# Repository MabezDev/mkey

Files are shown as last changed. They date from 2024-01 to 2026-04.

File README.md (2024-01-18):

## mKey

A mechanical keyboard based on an ESP32-S3, with firmware written in Rust.

[Click here to view the PCB & Schematic interactively in the browser](https://kicanvas.org/?github=https%3A%2F%2Fgithub.com%2FMabezDev%2Fmkey%2Ftree%2Fmain%2Fhardware%2Fboard)

## Flashing

The USB port is intended for flashing, as well as software USB usage. Version 1.0 of the board however has the DP and DM pins swapped, therefore to flash the board from the factory (or if the flash is wiped for any reason) you must flash via UART0. The pinout is as follows:

- TX is connected to the input side of D2 (COL1)
- RX is conncted to the input side of D3 (COL2)

## License

Licensed under either of:

- Apache License, Version 2.0 ([LICENSE-APACHE](LICENSE-APACHE) or http://www.apache.org/licenses/LICENSE-2.0)
- MIT license ([LICENSE-MIT](LICENSE-MIT) or http://opensource.org/licenses/MIT)
- CERN-OHL for the hardware files

at your option.

### Contribution

Unless you explicitly state otherwise, any contribution intentionally submitted for inclusion in
the work by you, as defined in the Apache-2.0 license, shall be dual licensed as above, without
any additional terms or conditions.

Contributions to the hardware will be licensed under the CERN-OHL license.

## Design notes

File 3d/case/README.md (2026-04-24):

# mKey Case — 3D Printing Build Guide

## Prerequisites

- [OpenSCAD](https://openscad.org/downloads.html) (CLI must be in `$PATH`)

## Quick Start

Export print-ready STLs for 3D printing:

```bash
cd 3d/case
./build_stl.sh
```

This produces `mkey_tray.stl` and `mkey_overlay.stl` in the current directory,
oriented for optimal printing (overlay flipped cosmetic-face-down, tray
bottom-down). Add supports in your slicer (Lychee, ChiTuBox, etc.).

> [!NOTE]
> **Run `./build_stl.sh` after every parameter or geometry change.** The
> build verifies that all assertions pass and that CGAL produces a valid
> mesh at production `$fn`. A clean OpenSCAD preview at low `$fn` does not
> guarantee a clean export — some CGAL errors only surface at `$fn=128`.

## Build Options

| Flag | Description |
|---|---|
| `--piece tray\|overlay\|both` | Which piece(s) to export (default: `both`) |
| `--fn N` | Circle resolution override (default: `128`; file preview default is `48`) |
| `--outdir DIR` | Output directory (default: `.`) |

## Print Orientation

The build script sets `PRINT_MODE=true`, which transforms the parts for
optimal 3D printing:

- **Overlay**: The 5-degree wedge tilt is removed so the part lies perfectly flat.
  The cosmetic face (key openings / display window) is flipped **down** toward
  the build plate — this gives the best surface finish on both SLA resin and FDM.

- **Tray**: Printed bottom-down (the bottom is already flat at Z=0). Add
  supports in the slicer — place them on outer walls and bottom only, not
  inside the cavity.

## Design Parameters (case.scad)

The main toggles in `case.scad` control which features are included:

| Toggle | Default | Purpose |
|---|---|---|
| `SHOW_TRAY` | `true` | Render the tray (bottom + walls) |
| `SHOW_OVERLAY` | `true` | Render the overlay (top surface) |
| `PRINT_MODE` | `false` | Re-orient pieces for 3D print export |
| `ENABLE_OVERLAY_RABBET` | `true` | Locating tongue/recess for X/Y registration |
| `ENABLE_MAGNET_POCKETS` | `true` | Blind magnet pockets for overlay hold-down |
| `ENABLE_SCREW_INSERTS` | `false` | M1.4 bolt + glued hex nut overlay retention (mutually exclusive with magnets) |
| `ENABLE_DECORATIVE_TRIMS` | `true` | Debossed logos, pinstripe, initials |

## JLC3DP SLA submission notes

> [!IMPORTANT]
> **X-AXIS SCALE COMPENSATION IS A HARD BUILD GATE.** Do not upload the
> STLs unless you have pasted the full order-note block below into the
> JLC3DP manufacturer-instructions field AND confirmed on the pre-build
> screenshot that JLC3DP applied the compensation on both pieces.
> Skipping this does not produce a looser fit — it produces parts that
> **physically cannot assemble**. The plate PCB is fabricated and frozen
> at its true size; the printed case without X-scale comp drifts up to
> ±1.09 mm over the 363 mm case length, which blows past every outer
> tolerance budget in the design (slot play, USB cheek, magnet margins).
>
> The geometry has belt-and-braces room for ±0.3 mm of residual post-
> compensation drift, not the raw ±1.09 mm uncompensated drift.

Paste the following instructions into the JLC3DP order-note / manufacturer-
instructions field when uploading `mkey_tray.stl` and `mkey_overlay.stl`.
Missing any of these will compromise fit or finish.

> Two-piece keyboard case, SLA standard resin.
>
> **MANDATORY — X-AXIS SCALE COMPENSATION ON BOTH PIECES:** Apply JLC3DP's
> per-batch X-axis scale compensation on BOTH `mkey_tray.stl` and
> `mkey_overlay.stl`. The case is 363 mm long and mates to a
> pre-fabricated FR4 PCB at tab positions spanning the full length; any
> asymmetric or uncompensated shrinkage will prevent assembly. Please
> confirm the compensation in your pre-build screenshots.
>
> **TRAY (mkey_tray.stl):**
> - Orient bottom-face DOWN on the build plate (the flat ~363 × 111 mm face).
>   Walls up, cavity open upward.
> - Factory supports on the outer side walls and outer bottom are acceptable.
>   **Do not add factory supports inside the cavity.**
> - The outer back wall carries a debossed "mKey" logo centred
>   horizontally, vertically between the bottom chamfer and the wall top
>   (~43 × 9 mm footprint). Please keep factory support contact points
>   clear of that debossed region if possible.
>
> **OVERLAY (mkey_overlay.stl):**
> - Orient cosmetic-face DOWN on the build plate (the face with the key
>   openings and display window). The underside, which carries the magnet
>   pockets (or hex nut pockets if using screw retention), faces up.
> - Place factory supports **only on the outer vertical side walls.** No
>   point supports on the downward-facing cosmetic face (key openings,
>   display window rim, pinstripe groove) and no supports inside the magnet
>   pockets, hex nut pockets, or display pocket on the up-facing underside. A raft under the
>   cosmetic face is acceptable provided the pinstripe groove and key
>   openings drain during post-processing (we IPA-flush these on our end).
> - **RAFT KEEP-OUT under the display window:** Please keep the raft
>   contact area clear of the ~32 × 38 mm region centred on the display
>   window cutout on the down-facing cosmetic face. The picture-frame
>   around the window is a 1.0 × 1.5 mm cross-grain rib — raft peel
>   forces can fracture it during support removal. An island of bare
>   build-plate under the window (with supports only on the surrounding
>   slab) is preferred.
>
> Please confirm orientations AND the X-axis scale compensation in the
> pre-build screenshots before starting the build.

**Why X-scale compensation is mandatory:** JLC3DP SLA has ±0.3% length
tolerance above 100 mm. At the 363 mm case X-axis that's ±1.09 mm worst
case, which would exceed the 0.6 mm slot tolerance on the outermost plate
tabs and shift the USB cutout off the receptacle body. With compensation,
residual drift is expected to stay inside the designed tolerances.

## Hand-finishing (post-delivery)

Order of operations when the parts arrive from JLC3DP:

1. **Inspect and photograph** factory support locations before removing
   anything — useful if a part has to be reordered.
2. **IPA-flush the resin-trap zones** with isopropanol and a soft brush
   *before* the final UV cure, if the factory hasn't already. These are
   recesses that sat against the build plate and may hold uncured resin:
    - Tray bottom underside: the `SM / 2026` owner-initials deboss.
    - Overlay cosmetic face: the pinstripe groove and (if enabled) the
      `DECO_LOGO_TOP` deboss.
3. **Snap off factory supports** from the tray bottom raft, tray outer
   walls, and overlay outer vertical walls. Expect witness nubbins —
   sand flat.
4. **Flush-sand the tray bottom** (raft side) with 120 → 240 → 400 grit,
   checking `SM / 2026` deboss legibility under raking light. Stop when
   legible; the 1.0 mm deboss depth tolerates ~0.3 mm of surface removal
   before legibility degrades.
5. **Light-sand the overlay outer vertical walls** (400 grit) to clean
   support nubbins. The cosmetic face should need only 800–1200 grit
   touch-up where any micro-support witness remains.
6. **Break the window edge** on the overlay with a fine file: the 1.0 mm
   shelf_frame_x on the display window long edges is at the brittle-
   fracture boundary under direct fingernail pressure during cleaning.
   A 0.2–0.3 mm edge break at all four window corners and edges
   multiplies its real-world durability.

## Fabrication Methods

**SLA resin (recommended)** — JLC3DP or equivalent. All tolerances and
minimum feature sizes are tuned for SLA's +/-0.2 mm accuracy. Add
supports in your slicer.

**MJF/SLS nylon** — NOT recommended. Loses the 1.0 mm shelf_frame_x display
window detail.

**FDM** — NOT suitable. Layer lines destroy the display cut tolerance and the
1.0 mm shelf frame sits below FDM's 1.6 mm wall minimum.

**Hand-cut hardwood** — Disable print-specific features:
```bash
# In case.scad or via -D flags:
ENABLE_DECORATIVE_TRIMS = false;
PRINT_MODE = false;
```

## Assembly

### Gasket install order

The plate is gasket-mounted: each of the 9 tabs is sandwiched between two
gasket strips inside its wall slot. Order matters — the plate cannot be
seated if the top gaskets are placed first.

1. **Bottom gaskets first.** Press a gasket strip into the bottom of each
   of the 9 slots before the plate goes in. These rest at the bottom of
   each slot, below where the tab will sit.
2. **Drop the plate in, front-first.** With 9 tabs engaging 9 slots
   simultaneously, a pure vertical descent is harder than a two-stage
   descent. Engage the 4 front tabs first (lower end of the tilted case),
   then **lower the plate straight down** — the 3 back tabs and 2 side
   tabs drop into their slots simultaneously. Do NOT pivot about the
   front tabs: a rotational descent swings the side tabs through ~3 mm
   of Z and can bind them against the wall top, which has only 1.5 mm
   of open-top margin. The 0.6 mm per-side slot tolerance accommodates
   the straight-down motion.
3. **Top gaskets second.** Press a second gasket strip onto the top of
   each tab, filling the remaining slot height.
4. **Overlay caps the stack.** Seating the overlay on the wall tops
   closes the open-top slots and compresses the top gaskets against the
   tabs, which compresses the tabs against the bottom gaskets.

### Magnet polarity

The overlay is held to the tray by six Ø2×1 mm N52 disc magnet pairs —
one per tray pocket and one per matching overlay pocket. Each pair must
**attract**, not repel, or the overlay will kick itself off the seat.

1. **Pick a reference magnet** from the bag and mark one face (dab of
   paint, sharpie dot). Set it aside.
2. **Tray magnets** — install every magnet with the **same face up** as
   the reference. Before each press-fit, hold the magnet face-up next to
   the reference: if they repel, flip it.
3. **Overlay magnets** — install with the **opposite face up**. When the
   overlay is flipped onto the tray, each overlay magnet then presents
   the attracting pole downward toward its tray mate. Test by holding
   the magnet with its eventual-up face touching the reference's
   marked face: it should **attract**.
4. **Glue each magnet FLUSH with the pocket mouth (critical).** The
   pockets are 2.0 mm deep for 1.0 mm magnets — if a magnet sinks to
   the pocket floor, the 1 mm recess on each side creates a 2 mm air
   gap that reduces holding force by ~90%. Place a flat reference plate
   (glass, steel straightedge) over the pocket mouth during CA cure so
   the magnet cures at the surface, not the bottom.
5. **Retain with thin CA glue (mandatory, not optional).** The 1.25 mm
   nominal cheek between pocket and outer wall (1.05 mm worst-case after
   SLA shrink) is too thin to rely on press-fit alone — any walk-out
   during thermal cycling or drop shock can chip the cheek. Use gel-type
   CA so it doesn't wick into the pocket and onto the seam, and press a
   strip of painter's tape across the pocket mouths during cure to prevent
   lift.

**Test before any glue cures.** With all 12 magnets placed but still
removable, lower the overlay onto the tray dry (no gaskets, no plate).
All six pairs should click together. If any pair repels, pop that
magnet out and flip it — catching this before the CA sets is much
cheaper than after.

### Screw + nut retention (alternative to magnets)

When `ENABLE_SCREW_INSERTS=true` (and `ENABLE_MAGNET_POCKETS=false`), the
overlay is secured by four M1.4 bolts threading up from inside the tray
into hex nuts glued into the overlay. Nothing is visible externally — bolt
heads sit in pockets on the tray underside (hidden against the desk),
and the overlay top surface is flush.

#### Hardware (4 of each)

| Qty | Part | Specification | Key dimensions |
|-----|---|---|---|
| 4 | Hex nut | M1.4 DIN 934 | 3.0 mm across-flats, 1.2 mm thick |
| 4 | Socket head cap screw | M1.4 × 14 mm | 2.6 mm head dia, 1.4 mm head height |

Same bolt length at all 4 positions. The bolt threads up from the tray
underside through the wall column and into the overlay nut. The through-
hole is a 4-segment stepped bore — no post-print drilling required:
- **Pocket** (3.4 mm dia, from tray bottom upward): bolt head sits here
- **Mid** (2.0 mm dia, intermediate): head catches on pocket→mid step
- **Lower clearance** (2.5 mm dia, 5.2 mm): wider pass-through
- **Upper clearance** (2.0 mm dia, 2.0 mm from wall top): shaft alignment

**Bolt length note:** M1.4 × 14 mm. The overlay nut pocket is 1.4 mm
deep — the 1.2 mm nut sits flush with the overlay underside (0.2 mm
tolerance headroom). 14 mm is the only standard M1.4 SHCS length that
simultaneously satisfies the mid-bore and back-pocket 3× depth rules;
12 mm fails the back pocket and 16 mm fails the mid bore.

Each segment stays within JLC3DP SLA depth limits (max 3× diameter) even
under worst-case ±0.3 mm hole-tolerance shrink.
At the back corners, the 10 mm chamfer removes the tray bottom; the
pocket starts from the chamfer face (deboss).

#### Nut installation

1. **Dry-fit first.** Drop each nut into its hex pocket on the overlay
   underside and confirm it sits flush with the surface. The pocket is
   only 0.2 mm deeper than the nut, so the nut should sit essentially
   flush by geometry. The hex shape should prevent rotation by hand.
   If a nut is tight, ream the pocket lightly with a needle file — do
   not force it.
2. **Glue with gel-type CA.** Apply a thin ring of gel CA around the
   pocket wall, press the nut in, and hold for 10 seconds. Wipe any
   squeeze-out immediately — excess CA on the overlay seating face will
   prevent the overlay from sitting flat on the tray.
3. **Do not use heat-set inserts.** SLA resin warps under soldering-iron
   temperatures. Glued hex nuts are the correct fastener for this process.

#### Final assembly

1. Complete the gasket + plate install (see above).
2. Seat the overlay on the tray wall tops (nuts face down, aligning
   with the clearance holes in the tray walls).
3. Flip the assembled case upside-down.
4. Insert the M1.4 × 14 mm bolts into all 4 pocket holes from below
   and tighten into the overlay nuts with a 1.25 mm hex key. Finger-
   tight plus a quarter turn is sufficient. **Hand-torque only — do
   NOT use a torque driver or electric screwdriver.** The bolt head
   bears on a 0.3 mm radial annulus between the Ø3.4 mm pocket and
   Ø2.0 mm mid segments (~2.2 mm² contact area); over-tightening will
   crush that step into the SLA resin and wander the pocket, which is
   not serviceable. If an overlay feels loose after the quarter turn,
   STOP and inspect — you will not fix it by tightening harder.
5. Flip the case back upright. The bolt heads sit in the pocket
   recesses on the tray underside, hidden against the desk.

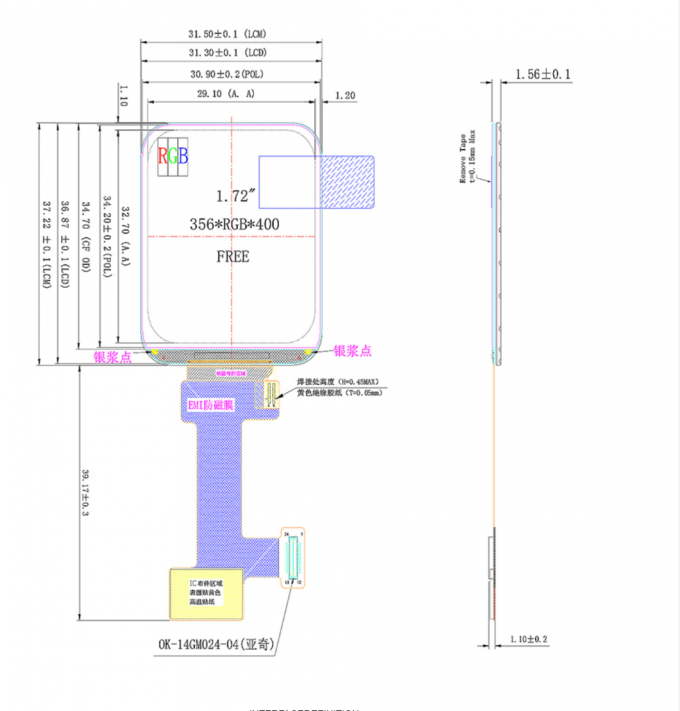
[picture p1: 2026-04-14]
hardware/board/assets/display-dimensions.png

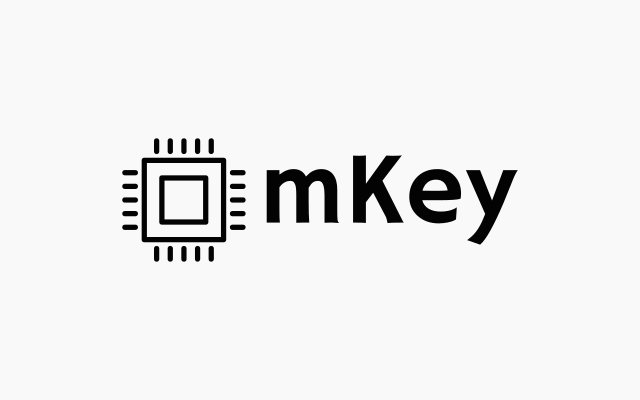
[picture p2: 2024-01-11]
hardware/board/assets/mkey.png

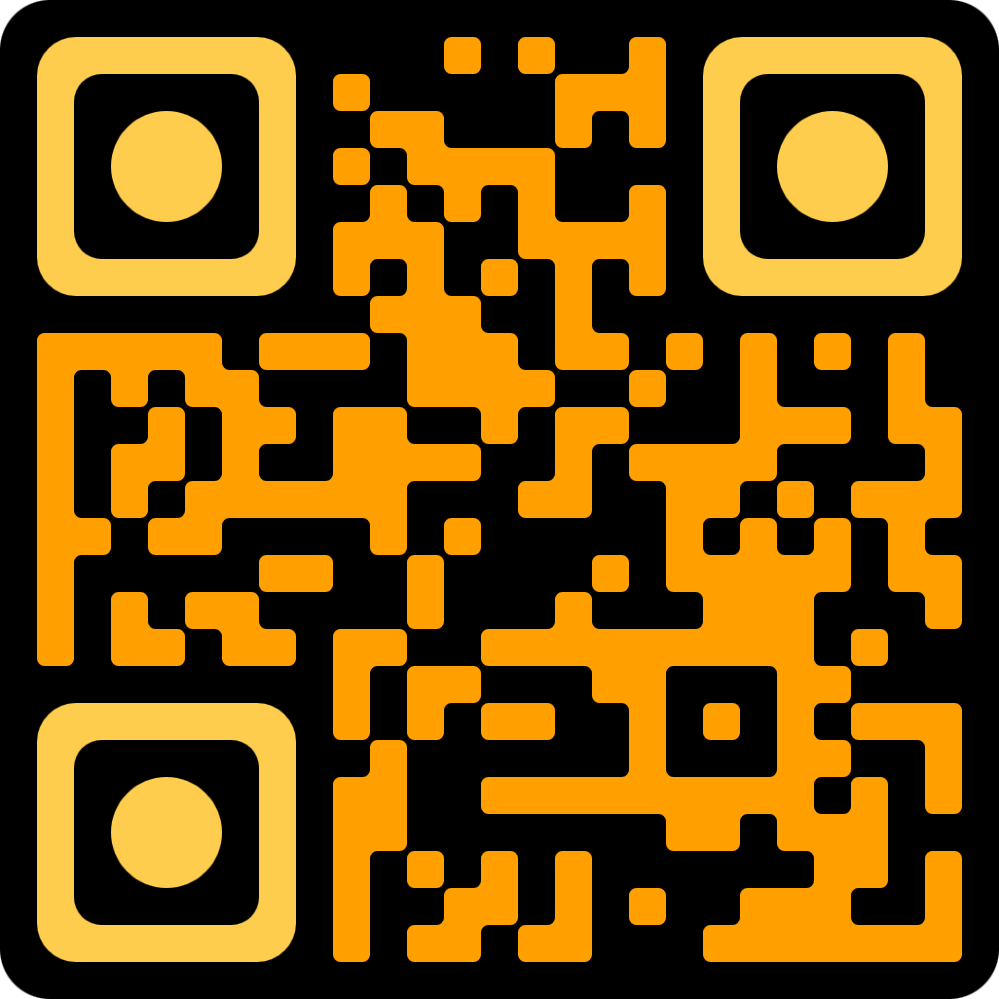
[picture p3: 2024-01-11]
hardware/board/assets/QR.png

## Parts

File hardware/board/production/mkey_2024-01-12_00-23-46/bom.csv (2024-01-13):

Designator | Footprint | Quantity | Value | LCSC Part #
_4, _3, _2, |  | 4
C1, C5 | 0603 | 2 | 1uF 16V | C52923
C2, C4 | 0805 | 2 | 10uF 16V | C15850
C3 | 0603 | 1 | 22pF 50V | C1653
C6 | 0603 | 1 | 100nF 10V | C1525
C7 | 0603 | 1 | 10nF 10V | C15195
D1, D10, D11, D12, D13, D14, D15, D16, D17, D18, D19, D2, D20, D21, D22, D23, D24, D25, D26, D27, D28, D29, D3, D30, D31, D32, D33, D34, D35, D36, D37, D38, D39, D4, D40, D41, D42, D43, D44, D45, D46, D47, D48, D49, D5, D50, D51, D52, D53, D54, D55, D56, D57, D58, D59, D6, D60, D61, D62, D63, D64, D65, D66, D7, D8, D9 | D_SOD-123 | 66 | D_Small
D67 | D_SOD-123 | 1 | B5819W | C8598
D68 | D_SOD-323 | 1 | PESD3V3L1BA,115
D69 | SOT-143 | 1 | SP0503BAHT
J1 | USB_C_Receptacle_HRO_TYPE-C-31-M-12 | 1 | USB_C_REP_2.0
J2 | CONN-SMD_24P-P0.40_X0400FVS-24-LPSN-LINEAR | 1 | 24 pin LCD FPC connector
L1 | L_Bourns-SRN4018 | 1 | SPH4018H2R2MT (2.2uH 2.2A) | C370436
MX1, MX10, MX11, MX12, MX13, MX14, MX16, MX17, MX18, MX19, MX2, MX20, MX21, MX22, MX23, MX24, MX25, MX26, MX27, MX28, MX3, MX30, MX31, MX32, MX33, MX34, MX35, MX36, MX37, MX38, MX39, MX4, MX40, MX41, MX43, MX44, MX45, MX46, MX47, MX48, MX49, MX5, MX50, MX51, MX52, MX53, MX54, MX55, MX59, MX6, MX64, MX65, MX66, MX7, MX8, MX9 | SW_MX_1u | 56 | MX_SW_solder
MX15 | SW_MX_1.5u | 1 | MX_SW_solder
MX29 | SW_MX_1.75u | 1 | MX_SW_solder
MX42, MX56, MX57, MX58, MX60, MX61, MX62, MX63 | SW_MX_1.25u | 8 | MX_SW_solder
R1, R2, R7 | 0603 | 3 | 10kR 1% | C25744
R3 | 0603 | 1 | 100kR 1% | C25741
R4 | 0603 | 1 | 22k1R 1% | C43473
R5, R6 | 0603 | 2 | 5k1R 1% | C25905
R8 | 0603 | 1 | 0R 1% | C17168
R9 | 0603 | 1 | 51.1R 1% | C25744
S1 | STAB_MX_P_6.25u | 1 | MX_stab
S2 | STAB_MX_P_2u | 1 | MX_stab
S4 | STAB_MX_P_2.75u | 1 | MX_stab
S5 | STAB_MX_ISO-ROT | 1 | MX_stab
SW0, SW1 | SW_SPST_PTS810 | 2 | SW_Push | C116501
U1 | ESP32-S3-WROOM-1 | 1 | ESP32-S3-WROOM-1
U2 | SOT-23-5 | 1 | SY8088 | C479072

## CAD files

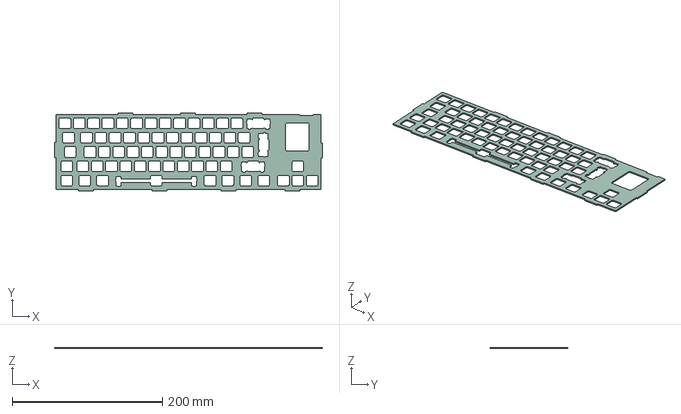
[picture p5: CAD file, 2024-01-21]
3d/plate.step
356.2 x 103.8 x 1.60 mm

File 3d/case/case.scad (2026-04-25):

// =============================================================================
// mKey Keyboard Case - OpenSCAD Design
// =============================================================================
// Premium darkwood case for the mKey 65% mechanical keyboard.
// Design: wedge profile, gasket-mounted plate, integrated display window.
// Style: sleek defined lines, minimal bezel, premium feel.
//
// FABRICATION TARGET — 3D PRINT PATH (JLC3DP SLA resin):
//   When fabricated by 3D print, the intended process is JLC3DP SLA resin
//   (standard photopolymer, e.g. 8001 / white resin). MJF/SLS nylon is NOT
//   suitable — it loses the 1.0 mm shelf_frame_x window detail. FDM is a
//   hard NO — layer lines destroy disp_cut_tol and the 1.0 mm shelf frame
//   sits below FDM's 1.6 mm wall minimum. Parameters in this file are tuned
//   to JLC3DP SLA's ±0.2 mm <100 mm / ±0.3% >100 mm tolerance band and
//   0.2 mm assembly-clearance rule; the 2026-04-14 pre-fab review
//   re-tightened disp_cut_tol and grew the locating tongue to clear those
//   rules with margin. Orient each piece bottom-up (cosmetic face away
//   from build plate); detailed print orientation is specified in the
//   manufacture notes.
//
// ╔════════════════════════════════════════════════════════════════════════╗
// ║  MANDATORY ORDER-NOTE REQUIREMENT — X-AXIS SCALE COMPENSATION         ║
// ║                                                                        ║
// ║  Before uploading `mkey_tray.stl` and `mkey_overlay.stl` to JLC3DP,   ║
// ║  you MUST paste the X-axis scale-compensation request into the        ║
// ║  order-note / manufacturer-instructions field. Without it, the parts  ║
// ║  will not assemble. This is not a preference; it is a hard build      ║
// ║  gate.                                                                 ║
// ║                                                                        ║
// ║  Why: the case outer_w is 363 mm. JLC3DP SLA tolerance over 100 mm    ║
// ║  is ±0.3% of the dimension → ±1.09 mm worst-case drift on X. The      ║
// ║  plate (FR4 PCB) is already fabricated and DOES NOT scale; printed    ║
// ║  slots at the outermost tabs can drift ~0.96 mm relative to their     ║
// ║  tabs, blowing past `slot_tol = 0.6 mm/side` and the 0.5 mm USB       ║
// ║  cheek and the 0.3 mm magnet-pocket wall margin. With per-piece       ║
// ║  X-scale compensation applied by JLC3DP, residual drift stays inside  ║
// ║  the tolerances the geometry was designed around.                     ║
// ║                                                                        ║
// ║  Action: see README.md §"JLC3DP SLA submission notes" — paste the     ║
// ║  full order-note block verbatim, do not abridge, and verify JLC3DP's  ║
// ║  pre-build screenshot confirms the scale compensation before          ║
// ║  production starts.                                                   ║
// ╚════════════════════════════════════════════════════════════════════════╝
//
// Coordinate system (case frame):
//   X = left to right (0 = left case edge)
//   Y = front to back (0 = front edge, positive toward back / USB side)
//   Z = up (0 = desk surface when case is sitting flat)
//
// Physical orientation (user sitting at keyboard):
//   Front (Y=0): spacebar row, lower edge (close to user)
//   Back (Y=max): number row, USB port, higher edge (away from user)
//   Right (X=max): display area, arrow keys
//   Left (X=0): Esc key side
// =============================================================================

$fn = 48;

// ─── Rendering switches ──────────────────────────────────────────────────────
SHOW_TRAY       = true;    // piece 1: bottom + walls
SHOW_OVERLAY    = true;    // piece 2: top surface
SHOW_PLATE      = false;   // ghost plate for fit check
SHOW_DISPLAY    = false;   // ghost display for fit check
SHOW_SECTION    = false;   // cross-section cut for inspection
EXPLODE         = 2;       // set >0 to separate overlay from tray (mm)

// ─── Print-mode switches ────────────────────────────────────────────────────
// When PRINT_MODE is true, the assembly renders print-oriented pieces:
//   - Overlay is flattened (6° tilt removed), bottom-up (pockets face up)
//   - Tray is unchanged in orientation (bottom is already flat)
// When exporting STLs for manufacturing, set PRINT_MODE=true and render one
// piece at a time (SHOW_TRAY xor SHOW_OVERLAY).
PRINT_MODE      = false;   // flip to true (or pass -D) for STL export

// ─── Feature toggles (per-fabrication-method overrides) ─────────────────────
// DESIGN NOTE — why these are toggles:
//   The case may be fabricated by two very different methods depending on the
//   build: (a) hand-cut hardwood using saw/drill/file/chisel, or (b) 3D-printed
//   plastic (FDM/SLA). Some features are trivial in one method and painful in
//   the other. A rabbet on the tray wall top to locate the overlay is ~5
//   minutes on a 3D-printer but a fiddly chisel operation in hardwood; blind
//   magnet pockets are laughably easy on a printer but need a drill-press stop
//   in wood. Rather than forking the file, every optional locating/retention
//   feature is behind a toggle so you can flip them per build without editing
//   the geometry. This is the real power of the file: one source, multiple
//   fabrication paths, with the asserts still covering all configurations.
ENABLE_OVERLAY_RABBET = true;    // cut a shallow rabbet in the tray wall top
                                 // that the overlay overhang seats into for
                                 // X/Y registration. Trivial on a printer,
                                 // chisel work in hardwood.
ENABLE_MAGNET_POCKETS = true;    // cut blind magnet pockets in the tray wall
                                 // top AND matching pockets in the overlay
                                 // underside, so the two pieces hold together
                                 // magnetically (serviceable — overlay lifts
                                 // off for PCB access). Counts on N52 disc
                                 // magnets — see magnet_* params below.
ENABLE_SCREW_INSERTS  = false;   // M1.4 hex nuts (glued) in hex pockets in the
                                 // overlay underside + bolts threading up from
                                 // the tray underside. 4 corner positions.
                                 // Mutually exclusive with ENABLE_MAGNET_POCKETS.

// ─── Decorative trims (3D-print-only) ───────────────────────────────────────
// Cosmetic embellishments with no mechanical role. Only practical on printed
// builds — hand-fabrication in hardwood can't render fine text/grooves cleanly.
// Every cut is sized to satisfy JLC3DP's design rules (≥0.8 mm wide AND
// ≥0.8 mm deep for any engraved or embossed detail, on both SLA resin and
// MJF nylon). ENABLE_DECORATIVE_TRIMS is the master gate: flipping it false
// silently drops every decorative cut, so hardwood builds or "naked" prints
// use the exact same file with one toggle.
ENABLE_DECORATIVE_TRIMS = true;   // master switch — false = all decoratives off
DECO_BACK_LOGO          = true;   // mKey logo debossed on outer back wall
DECO_EDGE_PINSTRIPE     = false;  // hairline groove around the overlay top edge
DECO_OWNER_INITIALS     = true;   // initials + year debossed into the tray underside
DECO_LOGO_TOP           = false;   // mKey logo debossed on overlay top above the display
DECO_INITIALS           = "SM";   // user-customisable owner initials
DECO_YEAR               = "2026"; // build year stamped under the initials

// =============================================================================
// SECTION 1: PLATE DIMENSIONS (from plate.kicad_pcb)
// =============================================================================
// The plate is the primary mounting reference. All case geometry derives from it.
//
// Plate KiCad coords:
//   Inner boundary: X 0.588..353.226, Y -107.641..-7.416
//   KiCad Y axis: negative, more negative = further up on screen = BACK of keyboard
//
// Plate-local coords (used in this file):
//   X_local = KiCad_X - 0.588       (0 = left plate edge)
//   Y_local = |KiCad_Y| - 7.416     (0 = front plate edge, plate_d = back)

plate_w = 352.638;   // inner boundary width  (353.226 - 0.588)
plate_d = 100.225;   // inner boundary depth  (107.641 - 7.416)
plate_t = 1.6;       // FR4 thickness

// ─── Mounting tabs ───────────────────────────────────────────────────────────
// Tabs extend beyond the inner boundary for gasket mounting.
// All positions in plate-local coordinates.
tab_len = 19.80;      // each tab is 19.80mm along its edge (measured in plate.kicad_pcb)
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

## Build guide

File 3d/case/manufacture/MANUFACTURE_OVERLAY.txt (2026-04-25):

X-axis scale compensation mandatory — ~350mm part, uncompensated shrinkage prevents mating.

Orientation: 26° X, 45° Z.

Supports: OK on underside flat areas away from pockets and perimeter edges. Heavy on underside to resist warping.

NO supports: top face (keycap side).

NO supports/sanding/blasting: display window rim, display pocket, 6 magnet pockets or 4 nut pockets (underside), rabbet recess (underside).

Confirm orientation and supports with screenshots before printing.

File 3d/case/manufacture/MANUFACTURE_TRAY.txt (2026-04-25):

X-axis scale compensation mandatory — ~350mm, shrinkage prevents mating.

Orientation: 26° X, 45° Z.

Drain holes: if needed, use rubber-pad recesses on underside.

Supports OK: outer walls, underside, perimeter edges, cavity. Heavy on underside for warp resistance.

NO supports/sanding/blasting: 9 gasket slots (inner walls), magnet pockets or screw holes (wall tops), USB-C cutout, rabbet tongue, debossed logo (back wall).

Confirm orientation and supports with screenshots.

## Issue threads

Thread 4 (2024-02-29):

Revision 1 board issues

MabezDev, 2024-02-29:
- [x] USB pins swapped
- [ ] Antenna clearance not enough
- [ ] Display CS tied to ground, CS is required to synchronize the display chip.

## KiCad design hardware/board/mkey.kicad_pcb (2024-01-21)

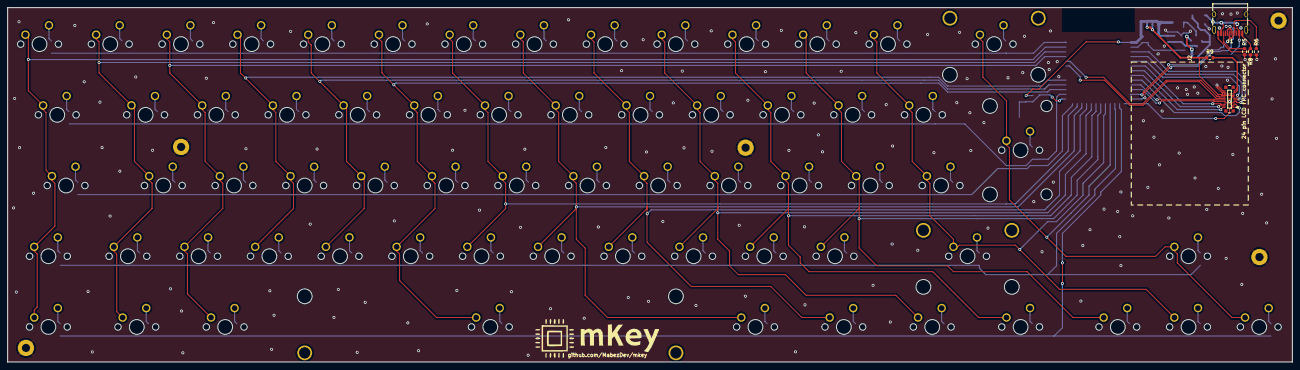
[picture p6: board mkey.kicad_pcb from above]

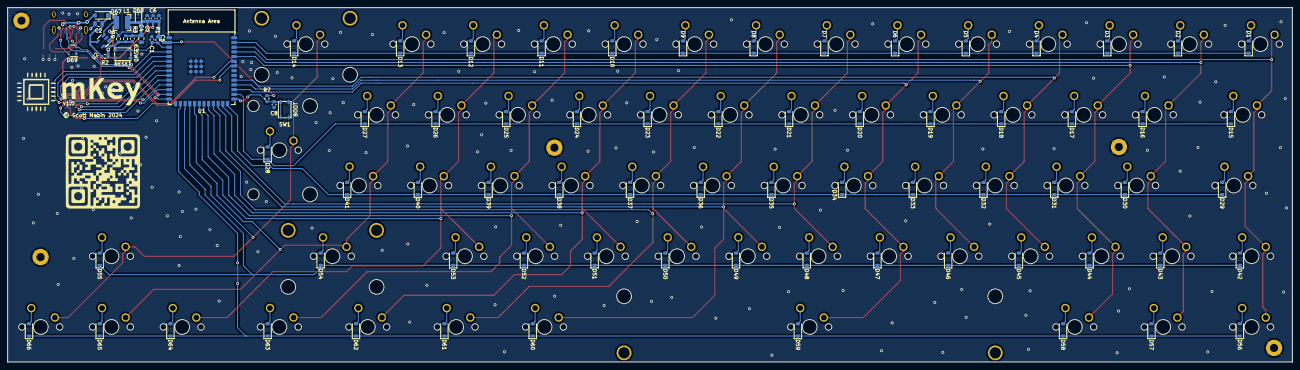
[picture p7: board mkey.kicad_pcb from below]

Board: 2 copper layers, 346.2 x 95.5 mm, 163 parts (87 on the bottom side), 112 nets.

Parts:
C1, C5: 1uF 16V; C_0603_1608Metric
C2, C4: 10uF 16V; C_0805_2012Metric
C3: 22pF 50V; C_0603_1608Metric
C6: 100nF 10V; C_0603_1608Metric
C7: 10nF 10V; C_0603_1608Metric
C8: 1nF 10V; C_0603_1608Metric
D1, D2, D3, D4, D5, D6, D7, D8, D9, D10, D11, D12, D13, D14, D15, D16, D17, D18, D19, D20, D21, D22, D23, D24, D25, D26, D27, D28, D29, D30, D31, D32, D33, D34, D35, D36, D37, D38, D39, D40, D41, D42, D43, D44, D45, D46, D47, D48, D49, D50, D51, D52, D53, D54, D55, D56, D57, D58, D59, D60, D61, D62, D63, D64, D65, D66: D_Small; D_SOD-123
D67: B5819W; D_SOD-123
D68: PESD3V3L1BA,115; D_SOD-323
D69: SP0503BAHT; SOT-143
J1: USB_C_REP_2.0; USB_C_Receptacle_HRO_TYPE-C-31-M-12
J2: 24 pin LCD FPC connector; CONN-SMD_24P-P0.40_X0400FVS-24-LPSN-LINEAR
L1: SPH4018H2R2MT (2.2uH 2.2A); L_Bourns-SRN4018
MX1, MX2, MX3, MX4, MX5, MX6, MX7, MX8, MX9, MX10, MX11, MX12, MX13, MX14, MX16, MX17, MX18, MX19, MX20, MX21, MX22, MX23, MX24, MX25, MX26, MX27, MX28, MX30, MX31, MX32, MX33, MX34, MX35, MX36, MX37, MX38, MX39, MX40, MX41, MX43, MX44, MX45, MX46, MX47, MX48, MX49, MX50, MX51, MX52, MX53, MX54, MX55, MX59, MX64, MX65, MX66: MX_SW_solder; SW_MX_1u
MX15: MX_SW_solder; SW_MX_1.5u
MX29: MX_SW_solder; SW_MX_1.75u
MX42, MX56, MX57, MX58, MX60, MX61, MX62, MX63: MX_SW_solder; SW_MX_1.25u
R1, R2, R7: 10kR 1%; R_0603_1608Metric
R3: 100kR 1%; R_0603_1608Metric
R4: 22k1R 1%; R_0603_1608Metric
R5, R6: 5k1R 1%; R_0603_1608Metric
R8: 0R 1%; R_0603_1608Metric
R9: 51.1R 1%; R_0603_1608Metric
S1: MX_stab; STAB_MX_P_6.25u
S2: MX_stab; STAB_MX_P_2u
S4: MX_stab; STAB_MX_P_2.75u
S5: MX_stab; STAB_MX_ISO-ROT
SW0, SW1: SW_Push; SW_SPST_PTS810
U1: ESP32-S3-WROOM-1
U2: SY8088; SOT-23-5

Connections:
+3V3: C3.1, C4.1, C5.1, C6.1, C7.1, D68.2 (A2), J2.9, J2.10, J2.15, J2.16, L1.2, R1.1, R3.1, R7.1, R9.2, U1.2 (3V3)
/Buck_Coil: L1.1, U2.3 (LX)
BOOT: C8.2, R7.2, SW1.1, U1.27 (GPIO0/BOOT)
CHIP_PU: C1.1, R1.2, SW0.1, U1.3 (EN)
COL0: MX1.1, MX15.1, MX29.1, MX42.1, MX56.1, U1.38 (GPIO2/TOUCH2/ADC1_CH1)
COL1: MX2.1, MX16.1, MX30.1, MX43.1, MX57.1, U1.37 (U0TXD/GPIO43/CLK_OUT1)
COL2: MX3.1, MX17.1, MX31.1, MX44.1, MX58.1, U1.36 (U0RXD/GPIO44/CLK_OUT2)
COL3: MX4.1, MX18.1, MX32.1, MX45.1, U1.31 (GPIO38/FSPIWP/SUBSPIWP)
COL4: MX5.1, MX19.1, MX33.1, MX46.1, U1.30 (SPIDQS/GPIO37/FSPIQ/SUBSPIQ)
COL5: MX6.1, MX20.1, MX34.1, MX47.1, MX59.1, U1.29 (SPIIO7/GPIO36/FSPICLK/SUBSPICLK)
COL6: MX7.1, MX21.1, MX35.1, MX48.1, U1.25 (GPIO48/SPICLK_N/SUBSPICLK_N_DIFF)
COL7: MX8.1, MX22.1, MX36.1, MX49.1, MX60.1, U1.24 (GPIO47/SPICLK_P/SUBSPICLK_P_DIFF)
COL8: MX9.1, MX23.1, MX37.1, MX50.1, MX61.1, U1.23 (GPIO21)
COL9: MX10.1, MX24.1, MX38.1, MX51.1, MX62.1, U1.22 (GPIO14/TOUCH14/ADC2_CH3/FSPIWP/FSPIDQS/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)
COL10: MX11.1, MX25.1, MX39.1, MX52.1, MX63.1, U1.21 (GPIO13/TOUCH13/ADC2_CH2/FSPIQ/FSPIIO7/S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)
COL11: MX12.1, MX26.1, MX40.1, MX53.1, MX64.1, U1.20 (GPIO12/TOUCH12/ADC2_CH1/FSPICLK/FSPIIO6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)
COL12: MX13.1, MX27.1, MX41.1, MX54.1, MX65.1, U1.19 (GPIO11/TOUCH11/ADC2_CH0/FSPID/FSPIIO5/S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)
COL13: MX14.1, MX28.1, MX55.1, MX66.1, U1.18 (GPIO10/TOUCH10/ADC1_CH9/FSPICS0/FSPIIO4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)
GND: C1.2, C2.2, C4.2, C5.2, C6.2, C7.2, C8.1, D68.1 (A1), D69.1 (A), J1.S1 (SHIELD), J2.2, J2.4, J2.8, J2.13, J2.14, J2.21, R4.2, R5.2, R6.2, R8.2, SW0.2, SW1.2, U1.1 (GND), U1.40 (GND), U1.41 (GND), U2.2 (GND)
LCD_CLK: J2.5, U1.4 (GPIO4/TOUCH4/ADC1_CH3)
LCD_D/C: J2.24, U1.9 (GPIO16/U0CTS/ADC2_CH5/XTAL_32K_N)
LCD_RESET: J2.1, U1.15 (GPIO3/TOUCH3/ADC1_CH2)
LCD_SIO0: J2.7, U1.6 (GPIO6/TOUCH6/ADC1_CH5)
LCD_SIO1: J2.6, U1.5 (GPIO5/TOUCH5/ADC1_CH4)
LCD_SIO2: J2.23, U1.8 (GPIO15/U0RTS/ADC2_CH4/XTAL_32K_P)
LCD_SIO3: J2.22, U1.7 (GPIO7/TOUCH7/ADC1_CH6)
unnamed: D1.2 (A), MX1.2
unnamed: D2.2 (A), MX2.2
unnamed: D3.2 (A), MX3.2
unnamed: D4.2 (A), MX4.2
unnamed: D5.2 (A), MX5.2
unnamed: D6.2 (A), MX6.2
unnamed: D7.2 (A), MX7.2
unnamed: D8.2 (A), MX8.2
unnamed: D9.2 (A), MX9.2
unnamed: D10.2 (A), MX10.2
unnamed: D11.2 (A), MX11.2
unnamed: D12.2 (A), MX12.2
unnamed: D13.2 (A), MX13.2
unnamed: D14.2 (A), MX14.2
unnamed: D15.2 (A), MX15.2
unnamed: D16.2 (A), MX16.2
unnamed: D17.2 (A), MX17.2
unnamed: D18.2 (A), MX18.2
unnamed: D19.2 (A), MX19.2
unnamed: D20.2 (A), MX20.2
unnamed: D21.2 (A), MX21.2
unnamed: D22.2 (A), MX22.2
unnamed: D23.2 (A), MX23.2
unnamed: D24.2 (A), MX24.2
unnamed: D25.2 (A), MX25.2
unnamed: D26.2 (A), MX26.2
unnamed: D27.2 (A), MX27.2
unnamed: D28.2 (A), MX28.2
unnamed: D29.2 (A), MX29.2
unnamed: D30.2 (A), MX30.2
unnamed: D31.2 (A), MX31.2
unnamed: D32.2 (A), MX32.2
unnamed: D33.2 (A), MX33.2
unnamed: D34.2 (A), MX34.2
unnamed: D35.2 (A), MX35.2
unnamed: D36.2 (A), MX36.2
unnamed: D37.2 (A), MX37.2
unnamed: D38.2 (A), MX38.2
unnamed: D39.2 (A), MX39.2
unnamed: D40.2 (A), MX40.2
unnamed: D41.2 (A), MX41.2
unnamed: D42.2 (A), MX42.2
unnamed: D43.2 (A), MX43.2
unnamed: D44.2 (A), MX44.2
unnamed: D45.2 (A), MX45.2
unnamed: D46.2 (A), MX46.2
unnamed: D47.2 (A), MX47.2
unnamed: D48.2 (A), MX48.2
unnamed: D49.2 (A), MX49.2
unnamed: D50.2 (A), MX50.2
unnamed: D51.2 (A), MX51.2
unnamed: D52.2 (A), MX52.2
unnamed: D53.2 (A), MX53.2
unnamed: D54.2 (A), MX54.2
unnamed: D55.2 (A), MX55.2
unnamed: D56.2 (A), MX56.2
unnamed: D57.2 (A), MX57.2
unnamed: D58.2 (A), MX58.2
unnamed: D59.2 (A), MX59.2
unnamed: D60.2 (A), MX60.2
unnamed: D61.2 (A), MX61.2
unnamed: D62.2 (A), MX62.2
unnamed: D63.2 (A), MX63.2
unnamed: D64.2 (A), MX64.2
unnamed: D65.2 (A), MX65.2
unnamed: D66.2 (A), MX66.2
unnamed: D67.2 (A), D69.4 (K), J1.A4 (VBUS), J1.A9 (VBUS), J1.B4 (VBUS), J1.B9 (VBUS)
unnamed: J1.A5 (CC1), R6.1
unnamed: J1.B5 (CC2), R5.1
unnamed: J1.A1 (GND), J1.A12 (GND), J1.B1 (GND), J1.B12 (GND), R8.1
unnamed: J2.11, J2.12, R9.1
unnamed: R2.2, U2.1 (EN)
unnamed: C3.2, R3.2, R4.1, U2.5 (FB)
ROW0: D1.1 (K), D2.1 (K), D3.1 (K), D4.1 (K), D5.1 (K), D6.1 (K), D7.1 (K), D8.1 (K), D9.1 (K), D10.1 (K), D11.1 (K), D12.1 (K), D13.1 (K), D14.1 (K), U1.39 (GPIO1/TOUCH1/ADC1_CH0)
ROW1: D15.1 (K), D16.1 (K), D17.1 (K), D18.1 (K), D19.1 (K), D20.1 (K), D21.1 (K), D22.1 (K), D23.1 (K), D24.1 (K), D25.1 (K), D26.1 (K), D27.1 (K), D28.1 (K), U1.28 (SPIIO6/GPIO35/FSPID/SUBSPID)
ROW2: D29.1 (K), D30.1 (K), D31.1 (K), D32.1 (K), D33.1 (K), D34.1 (K), D35.1 (K), D36.1 (K), D37.1 (K), D38.1 (K), D39.1 (K), D40.1 (K), D41.1 (K), U1.26 (GPIO45)
ROW3: D42.1 (K), D43.1 (K), D44.1 (K), D45.1 (K), D46.1 (K), D47.1 (K), D48.1 (K), D49.1 (K), D50.1 (K), D51.1 (K), D52.1 (K), D53.1 (K), D54.1 (K), D55.1 (K), U1.17 (GPIO9/TOUCH9/ADC1_CH8/FSPIHD/SUBSPIHD)
ROW4: D56.1 (K), D57.1 (K), D58.1 (K), D59.1 (K), D60.1 (K), D61.1 (K), D62.1 (K), D63.1 (K), D64.1 (K), D65.1 (K), D66.1 (K), U1.16 (GPIO46)
TEAR EFFECT: J2.3, U1.10 (GPIO17/U1TXD/ADC2_CH6)
TP_INT: J2.17, U1.35 (MTMS/GPIO42)
TP_RST: J2.18, U1.34 (MTDI/GPIO41/CLK_OUT1)
TP_SCL: J2.20, U1.12 (GPIO8/TOUCH8/ADC1_CH7/SUBSPICS1)
TP_SDA: J2.19, U1.11 (GPIO18/U1RXD/ADC2_CH7/CLK_OUT3)
USB_D+: D69.3 (K), J1.A6 (D+), J1.B6 (D+), U1.14 (GPIO20/U1CTS/ADC2_CH9/CLK_OUT1/USB_D+)
USB_D-: D69.2 (K), J1.A7 (D-), J1.B7 (D-), U1.13 (GPIO19/U1RTS/ADC2_CH8/CLK_OUT2/USB_D-)
VBUS: C2.1, D67.1 (K), R2.1, U2.4 (IN)

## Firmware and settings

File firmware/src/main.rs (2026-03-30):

#![no_std]
#![no_main]
#![feature(type_alias_impl_trait)]

use core::ptr::addr_of_mut;
use core::sync::atomic::Ordering;

use embassy_sync::blocking_mutex::raw::CriticalSectionRawMutex;
use embassy_sync::signal::Signal;
use embedded_graphics::geometry::Point;
use embedded_graphics::image::Image;
use embedded_graphics::Drawable;
use embedded_graphics_core::pixelcolor::Rgb565;
// esp-backtrace still linked for backtrace support, but our own panic handler
// in panic.rs saves the message to RTC memory before resetting.
use esp_hal::clock::CpuClock;
use esp_hal::dma::DmaRxBuf;
use esp_hal::dma::DmaTxBuf;
use esp_hal::dma_buffers;
use esp_hal::gpio::InputConfig;
use esp_hal::gpio::Level;
use esp_hal::interrupt;
use esp_hal::interrupt::software::SoftwareInterruptControl;
use esp_hal::interrupt::Priority;
use esp_hal::otg_fs::Usb;
use esp_hal::peripherals::Interrupt;
use esp_hal::system::Stack;
use esp_hal::time::Rate;
use esp_hal::timer::systimer::SystemTimer;
use esp_hal::timer::timg::TimerGroup;
use esp_hal::{
    delay::Delay,
    gpio::Io,
    gpio::{Input, Output, Pull},
    main,
    spi::{master::Spi, Mode},
};
use esp_rtos::{self, embassy::Executor};
use usbd_hid::descriptor::KeyboardReport;

use display::{
    lcd_fill, lcd_write_cmd, FRAME_BUFFER, HEIGHT, MAX_DMA_TRANSFER, TE, TE_READY,
    WEA2012_INIT_CMDS, WIDTH,
};

#[macro_export]
macro_rules! make_static {
    ($t:ty, $val:expr) => ($crate::make_static!($t, $val,));
    ($t:ty, $val:expr, $(#[$m:meta])*) => {{
        $(#[$m])*
        static STATIC_CELL: static_cell::StaticCell<$t> = static_cell::StaticCell::new();
        STATIC_CELL.init_with(|| $val)
    }};
}

esp_bootloader_esp_idf::esp_app_desc!();

// MUST be the first module so other modules see the macros
pub mod fmt;

mod display;
mod keyboard;
mod keymap;
mod logger;
mod panic;

static mut APP_CORE_STACK: Stack<8192> = Stack::new();

#[main]
fn main() -> ! {
    let peripherals = esp_hal::init(esp_hal::Config::default().with_cpu_clock(CpuClock::max()));

    let debug = cfg!(feature = "debug-matrix") || keyboard::is_debug_mode();

    // Check for panic from previous boot — message will be sent over CDC once USB enumerates
    panic::check_previous_panic();

    // Logger just pushes to a pipe — consumer (CDC or JTAG) is set up later on core 1
    logger::init();

    let delay = Delay::new();

    let timg0 = TimerGroup::new(peripherals.TIMG0);
    esp_rtos::start(timg0.timer0);

    let mut io = Io::new(peripherals.IO_MUX);
    io.set_interrupt_handler(display::te);
    interrupt::enable(Interrupt::GPIO, Priority::Priority2).unwrap();

    let sclk = peripherals.GPIO4;
    let sio0 = peripherals.GPIO6;
    let sio1 = peripherals.GPIO5;
    let sio2 = peripherals.GPIO15;
    let sio3 = peripherals.GPIO7;
    let cs = peripherals.GPIO16;
    let mut reset = Output::new(peripherals.GPIO3, Level::Low, Default::default());

    let mut te_pin = Input::new(
        peripherals.GPIO17,
        InputConfig::default().with_pull(Pull::Down),
    );
    te_pin.listen(esp_hal::gpio::Event::RisingEdge);
    critical_section::with(|cs| TE.borrow_ref_mut(cs).replace(te_pin));

    let (tx_buffer, tx_descriptors, rx_buffer, rx_descriptors) = dma_buffers!(MAX_DMA_TRANSFER, 1);

    let mut spi = Spi::new(
        peripherals.SPI2,
        esp_hal::spi::master::Config::default()
            .with_frequency(Rate::from_mhz(80))
            .with_mode(Mode::_3),
    )
    .unwrap()
    .with_sck(sclk)
    .with_mosi(sio0)
    .with_miso(sio1)
    .with_sio2(sio2)
    .with_sio3(sio3)
    .with_cs(cs)
    .with_dma(peripherals.DMA_CH0)
    .with_buffers(
        DmaRxBuf::new(rx_descriptors, rx_buffer).unwrap(),
        DmaTxBuf::new(tx_descriptors, tx_buffer).unwrap(),
    );

    reset.set_low();
    delay.delay_millis(300u32);
    reset.set_high();
    delay.delay_millis(300u32);

    // initialization commands
    for (cmd, data) in WEA2012_INIT_CMDS {
        lcd_write_cmd(&mut spi, *cmd, data);
    }
    info!("Finished initializing display!");

    let pixels = unsafe { &mut *addr_of_mut!(FRAME_BUFFER) };
    /*
       Matrix
    */
    let columns = make_static!(
        [Input<'static>; 14],
        [
            Input::new(
                peripherals.GPIO2,
                InputConfig::default().with_pull(Pull::Up)
            ), // 0
            Input::new(
                peripherals.GPIO43,
                InputConfig::default().with_pull(Pull::Up)
            ), // 1
            Input::new(
                peripherals.GPIO44,
                InputConfig::default().with_pull(Pull::Up)
            ), // 2
            Input::new(
                peripherals.GPIO38,
                InputConfig::default().with_pull(Pull::Up)
            ), // 3
            Input::new(
                peripherals.GPIO37,
                InputConfig::default().with_pull(Pull::Up)
            ), // 4
            Input::new(
                peripherals.GPIO36,
                InputConfig::default().with_pull(Pull::Up)
            ), // 5
            Input::new(
                peripherals.GPIO48,
                InputConfig::default().with_pull(Pull::Up)
            ), // 6
            Input::new(
                peripherals.GPIO47,
                InputConfig::default().with_pull(Pull::Up)
            ), // 7
            Input::new(
                peripherals.GPIO21,
                InputConfig::default().with_pull(Pull::Up)
            ), // 8
            Input::new(
                peripherals.GPIO14,
                InputConfig::default().with_pull(Pull::Up)
            ), // 9
            Input::new(
                peripherals.GPIO13,
                InputConfig::default().with_pull(Pull::Up)
            ), // 10
            Input::new(
                peripherals.GPIO12,
                InputConfig::default().with_pull(Pull::Up)
            ), // 11
            Input::new(
                peripherals.GPIO11,
                InputConfig::default().with_pull(Pull::Up)
            ), // 12
            Input::new(
                peripherals.GPIO10,
                InputConfig::default().with_pull(Pull::Up)
            ), // 13
        ]
    );
    let rows = make_static!(
        [Output<'static>; 5],
        [
            Output::new(peripherals.GPIO1, Level::Low, Default::default()), // 0
            Output::new(peripherals.GPIO35, Level::Low, Default::default()), // 1
            Output::new(peripherals.GPIO45, Level::Low, Default::default()), // 2
            Output::new(peripherals.GPIO9, Level::Low, Default::default()), // 3
            Output::new(peripherals.GPIO46, Level::Low, Default::default()), // 4
        ]
    );

    let sw_ints = SoftwareInterruptControl::new(peripherals.SW_INTERRUPT);
    esp_rtos::start_second_core(
        peripherals.CPU_CTRL,
        sw_ints.software_interrupt0,
        sw_ints.software_interrupt1,
        unsafe { &mut *addr_of_mut!(APP_CORE_STACK) },
        move || {
            let signal =
                &*make_static!(Signal<CriticalSectionRawMutex, KeyboardReport>, Signal::new());
            let executor = make_static!(Executor, Executor::new());

            if debug {
                let usb_serial =
                    esp_hal::usb_serial_jtag::UsbSerialJtag::new(peripherals.USB_DEVICE);
                let (_rx, tx) = usb_serial.split();
                executor.run(|spawner| {
                    spawner.must_spawn(keyboard::matrix(columns, rows, signal));
                    spawner.must_spawn(keyboard::jtag_drain(tx));
                });
            } else {
                let device = Usb::new(peripherals.USB0, peripherals.GPIO20, peripherals.GPIO19);
                executor.run(|spawner| {
                    spawner.must_spawn(keyboard::matrix(columns, rows, signal));
                    spawner.must_spawn(keyboard::usb(device, signal));
                });
            }
        },
    );

    let image =
        tinygif::Gif::<Rgb565>::from_slice(include_bytes!("../Ferris-240x240.gif")).unwrap();
    let mut start = SystemTimer::unit_value(esp_hal::timer::systimer::Unit::Unit0);
    let mut frames = 0;
    loop {
        for frame in image.frames() {
            let frame = Image::with_center(
                &frame,
                Point::new(WIDTH as i32 / 2, (HEIGHT as i32 / 2) - 40),
            );
            frame.draw(pixels).unwrap();

            // TE_READY won't get set until we mark that we're ready to flush a buffer
            critical_section::with(|cs| {
                TE_READY.store(false, Ordering::SeqCst);
                TE.borrow_ref_mut(cs).as_mut().unwrap().clear_interrupt();
            });
            // wait for next sync
            while !TE_READY.load(Ordering::SeqCst) {}

            let pixels = unsafe {
                core::slice::from_raw_parts(
                    pixels.data().as_ptr() as *const u8,
                    pixels.data().len(),
                )
            };
            let now = SystemTimer::unit_value(esp_hal::timer::systimer::Unit::Unit0);
            lcd_fill(&mut spi, pixels);
            trace!(
                "Time to fill display: {}ms",
                (SystemTimer::unit_value(esp_hal::timer::systimer::Unit::Unit0) - now)
                    / (SystemTimer::ticks_per_second() / 1024)
            );
            frames += 1;
            let now = SystemTimer::unit_value(esp_hal::timer::systimer::Unit::Unit0);
            if now.wrapping_sub(start) > SystemTimer::ticks_per_second() {
                start = now;
                info!("FPS: {}", frames);
                frames = 0;
            }
        }
    }
}

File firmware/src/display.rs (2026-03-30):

use core::cell::RefCell;
use core::ptr::addr_of_mut;
use core::sync::atomic::AtomicBool;
use core::sync::atomic::Ordering;

use critical_section::Mutex;
use embedded_graphics::framebuffer::buffer_size;
use embedded_graphics::framebuffer::Framebuffer;
use embedded_graphics::pixelcolor::raw::BigEndian;
use embedded_graphics::pixelcolor::raw::RawU16;
use embedded_graphics_core::pixelcolor::Rgb565;
use esp_hal::gpio::Input;
use esp_hal::spi::master::{Address, Command, DataMode};
use esp_hal::timer::systimer::SystemTimer;
use esp_hal::Blocking;
use esp_hal::{handler, ram};

pub type QSpiDisplay<'a> = esp_hal::spi::master::SpiDmaBus<'a, Blocking>;

pub const MAX_DMA_TRANSFER: usize = 32736 / 4;
pub const WIDTH: usize = 356;
pub const HEIGHT: usize = 400;

pub static TE: Mutex<RefCell<Option<Input<'static>>>> = Mutex::new(RefCell::new(None));
pub static TE_READY: AtomicBool = AtomicBool::new(false);

pub static mut FRAME_BUFFER: Framebuffer<
    Rgb565,
    RawU16,
    BigEndian,
    WIDTH,
    HEIGHT,
    { buffer_size::<Rgb565>(WIDTH, HEIGHT) },
> = Framebuffer::new();

#[handler]
pub fn te() {
    unsafe {
        static mut LAST: u64 = 0;
        let now = SystemTimer::unit_value(esp_hal::timer::systimer::Unit::Unit0);
        log::trace!(
            "TE fired! Interval: {}ms",
            (now - LAST) / (SystemTimer::ticks_per_second() / 1024)
        );
        LAST = now;
    }
    critical_section::with(|cs| TE.borrow_ref_mut(cs).as_mut().unwrap().clear_interrupt());
    TE_READY.store(true, Ordering::SeqCst);
}

#[ram]
pub fn lcd_fill<'a>(spi: &mut QSpiDisplay<'a>, pixels: &'static [u8]) {
    set_draw_area(spi, 0, 0, WIDTH as u16 - 1, HEIGHT as u16 - 1);
    for (i, pixels) in pixels.chunks(MAX_DMA_TRANSFER).enumerate() {
        // fifo size
        spi.half_duplex_write(
            DataMode::Quad,
            Command::_8Bit(0x32, DataMode::SingleTwoDataLines),
            Address::_24Bit(
                if i > 0 { 0x002C00 } else { 0x003C00 },
                DataMode::SingleTwoDataLines,
            ),
            0,
            &pixels,
        )
        .unwrap();
    }
}

#[ram]
pub fn lcd_write_cmd<'a>(spi: &mut QSpiDisplay<'a>, cmd: u32, data: &[u8]) {
    static mut BUF: [u8; 4] = [0u8; 4];
    let buf = unsafe { &mut *addr_of_mut!(BUF) };
    if data.len() > 0 {
        buf[..data.len()].copy_from_slice(&data);
    }
    log::trace!("Sending: {} => {:?}", cmd, &buf[..data.len()]);
    spi.half_duplex_write(
        DataMode::Single,
        Command::_8Bit(0x02, DataMode::Single),
        Address::_24Bit(cmd << 8, DataMode::Single),
        0,
        &&buf[..data.len()],
    )
    .unwrap();
}

#[ram]
fn set_draw_area<'a>(spi: &mut QSpiDisplay<'a>, x1: u16, y1: u16, x2: u16, y2: u16) {
    let cmds = [
        (
            0x2a,
            &[(x1 >> 8) as u8, x1 as u8, (x2 >> 8) as u8, x2 as u8][..],
        ),
        (
            0x2b,
            &[(y1 >> 8) as u8, y1 as u8, (y2 >> 8) as u8, y2 as u8][..],
        ),
    ];

    for (cmd, data) in cmds {
        lcd_write_cmd(spi, cmd, data);
    }
}

// CMD, data
pub const WEA2012_INIT_CMDS: &[(u32, &[u8])] = &[
    (0xFF, &[0x20, 0x10, 0x43]),
    (0x04, &[0x70]),
    (0xFF, &[0x20, 0x10, 0x10]),
    (0x0C, &[0x11]),
    (0x10, &[0x02]),
    (0x11, &[0x11]),
    (0x15, &[0x42]),
    (0x16, &[0x11]),
    (0x1A, &[0x02]),
    (0x1B, &[0x11]),
    (0x61, &[0x80]),
    (0x62, &[0x80]),
    (0x54, &[0x44]),
    (0x58, &[0x88]),
    (0x5C, &[0xcc]),
    (0x20, &[0x80]),
    (0x21, &[0x81]),
    (0x22, &[0x31]),
    (0x23, &[0x20]),
    (0x24, &[0x11]),
    (0x25, &[0x11]),
    (0x26, &[0x12]),
    (0x27, &[0x12]),
    (0x30, &[0x80]),
    (0x31, &[0x81]),
    (0x32, &[0x31]),
    (0x33, &[0x20]),
    (0x34, &[0x11]),
    (0x35, &[0x11]),
    (0x36, &[0x12]),
    (0x37, &[0x12]),
    (0x41, &[0x11]),
    (0x42, &[0x22]),
    (0x43, &[0x33]),
    (0x49, &[0x11]),
    (0x4A, &[0x22]),
    (0x4B, &[0x33]),
    (0xFF, &[0x20, 0x10, 0x15]),
    (0x00, &[0x00]),
    (0x01, &[0x00]),
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
    // touch For I2C
    (0xFF, &[0x20, 0x10, 0x50]),
    (0x05, &[0x00]),
    (0x00, &[0xA6]),
    (0x01, &[0xA6]),
    (0x08, &[0x55]),
    (0xFF, &[0x20, 0x10, 0x12]),
    (0x21, &[0xB4]), // set vcom
    (0xFF, &[0x20, 0x10, 0x00]),
    // ADD FOR QSPI/TP TEST
    (0x3A, &[0x05]), // Set 65K colour mode
    (0x11, &[0x00]),
    (0x29, &[0x00]),
];

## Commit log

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2024-01-18 qio working? can read back some values, one seems correct, the other does not match the reset value...
    [main.rs]
2024-01-19 imo everything is correct, time to wait for new display and or get logic analyser on it
    [main.rs]
2024-01-21 Fix plate dims, remove old plates, add new plate with prod files
    [designators.csv, mkey-plate.kicad_pcb, plate.kicad_pcb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]
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2024-01-21 move lib back to board, kicad doesn't seem to follow paths outside of the proj. Add 3d model to usb port
    [mkey.kicad_pcb]
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2026-03-29 add UK ISO keymap with debounced matrix scanning and proper HID reports
    Replace the placeholder 'always send A' logic with a full keymap-driven
    approach: a 5×14 KEYMAP table maps each (row, col) to HID keycodes and
    modifier bits, the matrix task debounces key state and builds complete
    KeyboardReports (6KRO + modifiers), and the USB task forwards them directly.
    [main.rs]
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2026-03-29 fix keymap to match schematic and add debug-matrix feature
    Align keymap with actual PCB wiring from KiCad schematic:
    - Enter switch is at (row1, col13), row2/col13 has no switch
    - Space switch is at (row4, col4), not spread across cols 3-8
    - MX60 (row4, col7) is RAlt, MX61 (row4, col8) is Fn placeholder
    - Empty matrix positions marked with __ instead of duplicate keycodes
    Add debug-matrix cargo feature that skips USB init (preserving JTAG
    serial logging) and logs key press/release events with HID codes.
    [main.rs]
2026-03-30 add Fn key debug combos and runtime debug mode switching
    Fn key (row 4, col 8) now acts as a firmware-level modifier:
    - Fn + Esc: software reset
    - Fn + Backspace: reset to USB download mode
    - Fn + D: toggle debug mode (persisted in RTC store register)
    Debug mode is now runtime-switchable: Fn+D sets a flag in RTC memory
    that survives soft resets, so the next boot skips USB OTG init and
    runs JTAG serial logging instead. Fn+D again clears the flag and
    reboots back to normal USB HID mode. The debug-matrix cargo feature
    still works as a compile-time override.
    When Fn is held, HID reports are suppressed (Fn is invisible to host).
    [main.rs]
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2026-03-30 remove usb-pin-exchange from defaults and clean up debug logging
    The usb-pin-exchange pullup workaround was causing USB OTG PHY init
    to hang in Bus::init() busy-wait. Board has the HW fix applied so
    the feature is no longer needed by default.
    [main.rs]
2026-03-30 add panic-to-RTC-memory handler for post-crash diagnostics
    Custom panic handler saves the panic message to RTC slow memory
    (survives software resets), then resets the chip. On next boot,
    check_previous_panic() reads it back and prints over JTAG serial
    before USB OTG takes over the pins.
    This lets us see crash messages even though JTAG serial is normally
    unavailable once USB HID is running.
    [main.rs]
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2026-03-30 add USB CDC serial for log output, replace esp-println with custom backend
    USB composite device now exposes both HID keyboard and CDC ACM serial.
    Log output is piped to the CDC serial port via an embassy_sync::Pipe.
    Custom log backend (src/log.rs):
    - Normal mode: formats to 128-byte stack buffer, try_write to CDC pipe
    - Debug mode: writes directly to USB-SERIAL-JTAG FIFO via PAC
    Panic handler (src/panic.rs):
    - check_previous_panic() now returns bool
    - take_panic_message() provides one-shot access for CDC output
    - Saved panic messages sent over CDC on first USB connection
    Removes esp-println and esp-backtrace dependencies — all logging
    and panic handling is now self-contained.
    [main.rs]
2026-03-30 use proper UsbSerialJtag HAL driver, remove esp-println/esp-backtrace
    Replace raw PAC JTAG serial writes with esp-hal's UsbSerialJtag driver
    which properly enables the peripheral clock and handles the USB_EXCHG_PINS
    efuse pullup workaround automatically.
    The usb-pin-exchange feature and manual workaround in main.rs are now
    redundant — UsbSerialJtag::new() detects the efuse and applies the fix.
    Logger stores UsbSerialJtagTx in a static behind a critical section
    for safe access from both cores and the panic handler.
    [main.rs]
2026-03-30 fix boot hang: use non-blocking JTAG writes, remove 10s delay
    Three issues causing boot hang:
    - UsbSerialJtagTx::write() blocks waiting for host to read FIFO;
    switch to write_byte_nb/flush_tx_nb which drop data if FIFO full
    - check_previous_panic() was doing blocking JTAG serial writes;
    remove them, let CDC task handle output after USB enumerates
    - 10-second delay on panic detection removed; display starts immediately
    [main.rs]
2026-03-30 clean redesign: logger writes to pipe, consumers drain it
    Logger (log.rs) is now trivial: format to stack buffer, try_write to
    a static Pipe. No HAL types, no mode switching, no statics with
    interior mutability.
    Consumer depends on boot mode:
    - Normal: CDC writer (in usb task) drains pipe to USB serial port
    - Debug: jtag_drain task drains pipe to UsbSerialJtagTx
    Early boot panic dump writes directly to UsbSerialJtag in main()
    before the logger is even initialized — completely separate path.
    UsbSerialJtag is dropped before USB OTG init in normal mode, or
    split and passed to jtag_drain in debug mode.
    [main.rs]
2026-03-30 rename log module to logger to avoid shadowing the log crate
    mod log shadowed the log crate, causing ::log:: resolution issues
    that crashed on boot when log::init() was called. Renaming to
    logger eliminates the ambiguity.
    [main.rs]
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2026-04-02 rework case: overlay overhang, display mount, clean walls
    - Top overlay overhangs tray walls by 4mm on all sides with rounded
    corners (3mm radius) for a premium shadow-line aesthetic
    - Replace L-shaped key opening with full rectangle + display housing
    peninsula (rounded inner corner), eliminating structurally weak
    thin connecting strip
    - Rework display mounting for bottom-insertion assembly: viewing
    window sized to active area with rounded corners, module pocket
    with rounded corners and FPC ribbon channel, uniform lip thickness
    - Simplify wall step: remove rabbet lip, shorten walls by top_t so
    overlay sits flush on wall tops with no visible step
    - Remove FPC routing slot from ove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
    [case.scad]
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2026-04-09 cut key opening as union of per-keycap rectangles
    Replaces the single inner-rectangle key opening (with a carved-out
    display housing and separate arrow-key cutouts) with a union of
    per-row / per-cluster keycap footprints taken directly from
    mkey.kicad_pcb. Anywhere a key lives the overlay is cut through;
    everywhere else stays solid hardwood so the bare plate is hidden.
    Natural layout gaps become real bezels:
    * 4.76 mm between the main field and the arrow L/D/R row
    * 23.81 mm between R-shift and the UP arrow column
    * >=13.86 mm between the main field and the display housing
    This removes the need for the arrow_key_cutouts module, the tabbed
    display_housing_2d shape, and the FPC ribbon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
    [case.scad]
2026-04-13 fix case geometry bugs found in pre-fab design review
    The previous plate_z formula (top_z − plate_recess) placed the plate
    tabs 1.5 mm inside solid overlay material and made the gasket slots
    functionally 1.85 mm tall. Rewrote as top_z − top_t − plate_recess so
    the plate sits fully inside the tray with gasket headroom.
    slot_height now reaches 0.5 mm above the tray wall top, turning each
    slot into an open-top channel the tab can descend through. Guarded
    by a compile-time assert so any future bump to plate_recess without
    a matching slot bump fails at OpenSCAD load time.
    Replaced the 1.2 mm hardwood display lip (short-grain 2.2×1.2 mm
    cross-section, not survivable and not hand-cuttable)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
    [case.scad]
2026-04-13 strengthen overlay rib and rework display housing
    Two issues caught in the pre-fab design review needed case-only fixes
    (the plate and PCB are fabricated and out of scope):
    - the 4.16 mm main-field ↔ arrow-L/D/R rib in the overlay was the
    weakest cross-section in the whole case. Bumping top_t 3.0 → 5.0 mm
    gives 2.78× bending stiffness on that rib (section modulus scales
    with thickness²), and is ~17× stronger combined with a fab
    instruction to orient the overlay blank with grain running along Y.
    - the display housing was rebuilt to seat the module from below
    against a 1 mm wood shelf, with the active-area window cut through
    that shelf from above. Previously the module thr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
    [case.scad]
2026-04-13 thicken display shelf with curved asymmetric frame
    The uniform 0.8 mm shelf picture frame was the weakest part of the
    overlay after the stepped display cut landed. X is constrained to
    1.20 mm by the module bezel, but Y has 2.26 mm of bezel to work with,
    so the shelf is split into independent shelf_frame_x / shelf_frame_y:
    - shelf_frame_x bumped 0.8 → 1.0 mm (+25% on the long edges,
    where the weakest beams live)
    - shelf_frame_y bumped 0.8 → 1.6 mm (+100% on the short edges)
    - new shelf_corner_r = 1.2 mm smooths the corner where the two
    widths meet — no sharp notch
    The window is now built as a hull() of four shelf_corner_r circles
    sitting in the window-bbox corners, so the inner ed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
    [case.scad]
2026-04-13 fix gasket slot drop-in failure under tilt and thin wall cheek
    L/R gasket slots run along the 5° tilt axis. With slot_open_margin=0.5 mm
    and a 20.10 mm slot length, the wall top rises 0.88 mm above slot center
    at the uphill end — so the flat-topped slot box was sealed by wall material
    on the back third of its length and the plate physically could not drop in
    on the left or right side. Bump slot_open_margin to 1.5 mm so the slot top
    clears the uphill wall top by 0.62 mm (well above ±0.2 mm fab slop).
    Separately, slot_depth=2.5 mm into 4.8 mm walls left only a 2.3 mm
    outboard cheek, cross-grain to bending and a chip-off hazard with seven
    20 mm slots cut along the front+back walls. Tab pen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
    [case.scad]
2026-04-13 move measurement verification into SCAD asserts and thicken display shelf
    Pre-fab design review (teams of audit agents):
    - Bump shelf_t 1.0 → 1.5 mm. The 1.0 × 1.6 × 30 mm cross-grain short
    beams had a bending SF < 1 against a 1 N poke and were shop-fragile
    in hardwood. Stiffness ∝ t³, so this is a 3.4× win. Pocket depth
    drops 4.0 → 3.5 mm, still above the 1.56 mm module glass.
    - Port every gap in verify_measurements.py into inline SCAD asserts:
    slot-tilt clearance, wall cheek, tab-extension vs slot depth,
    chamfer ≤ top_t, overhang ≤ wall_t, arrow-LDR rib ≥ 4 mm after
    key_cap_clearance, top_t − shelf_t ≥ disp_glass_t, USB cut Z
    within the back-wall Z range.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
    [case.scad]
2026-04-13 expand SCAD asserts and fix cleanups from pre-fab review
    Pre-fabrication design review (measurement, STEP fit-check, assembly,
    structural, assert-coverage agents) confirmed every dimensioned constant
    matches plate.kicad_pcb and plate.step to ≤0.0004 mm and all 66 keycaps
    fit. Remaining cleanup items land here.
    - Add 7 CRITICAL invariants that were implied but unchecked: USB cutout X
    bounds on the back wall cheek, main-field ↔ display-pocket bezel ≥ 4 mm,
    active area centered in module, retainer thickness vs glass in pocket,
    bottom pad recess floor ≥ 2 mm under fab slop, key_rects inside plate
    bounds, tilt_angle supported range.
    - Fix the chamfer assert: it was checking `cham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
    [case.scad]
2026-04-14 add overlay locating tongue + magnet pocket features
    Adds two optional features (both behind toggles at the top of case.scad) to
    lock the overlay to the tray instead of relying on gasket friction alone:
    - ENABLE_OVERLAY_RABBET: an inverted "tongue" on the tray wall top inside
    edge that drops into a matching recess in the overlay underside. The
    tongue/recess ring is notched at each of the 9 gasket slot Y locations
    so the plate-tab drop-in path stays clear.
    - ENABLE_MAGNET_POCKETS: 4 blind pockets in the tray wall top and overlay
    underside for 3 mm N52 disc magnets (one near each case corner).
    Feature toggles let the same source drive both 3D-printed and hand-cut
    hardwood builds wit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
    [case.scad]
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2026-04-14 fix side-slot downhill gasket starvation from tilt drift
    Pre-fab design review caught a case where the side (left/right) gasket slots
    run along the 5° tilt axis, so the flat-bottomed slot box loses
    (tab_len+slot_tol)/2 · tan(5°) ≈ 0.88 mm of bottom-gasket headroom at the
    downhill end. With the prior slot_bot_below_plate = 1.75 mm that left only
    0.87 mm below the plate for a 1.5 mm compressed gasket — crushing it. This is
    the symmetric counterpart of the existing slot_open_margin check at the
    uphill top of the slot.
    Also bundles the other non-blocking findings from the same review:
    - slot_tol 0.3 → 0.4 mm so worst-case ±0.2 mm fab slop still leaves play
    - magnet_inset 15 → 13 mm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
    [case.scad]
2026-04-14 tune case tolerances for JLC3DP SLA pre-fab review
    Raise disp_cut_tol 0.15 → 0.20 to clear JLC3DP's 0.2 mm assembly-
    clearance rule under SLA's ±0.2 mm <100 mm tolerance; worst-case pocket
    shrink goes from 0.05 mm interference to 0.0 mm clearance. Grow the
    overlay locating tongue from 1.3 × 1.0 mm to 1.5 × 1.5 mm to meet
    JLC3DP's 1.5 mm recommended minimum for positioning/snap features on
    SLA. Pin the intended 3D-print process in the file header so future
    edits don't regress below the rules (MJF/SLS kills the 1.0 mm shelf
    frame; FDM is hard-incompatible).
    [case.scad]
2026-04-14 fix magnet pocket sliver from tilt drift
    The tray wall top and overlay underside are both tilted 5° about X,
    but tray_magnet_pockets / overlay_magnet_pockets were cutting vertical
    Ø3.2 mm cylinders anchored at the wall_top Z of the pocket CENTER Y.
    Over the 3.2 mm pocket diameter the tilted plane drifts by
    magnet_d · tan(5°) ≈ 0.28 mm, so on the tray a ~0.14 mm sliver of
    wall-top material capped the uphill (cavity-side) rim of each pocket,
    and on the overlay a ~0.14 mm sliver of underside material sat below
    the downhill rim.
    Anchor the tray cylinder top to top_z(p[1] + magnet_d/2) − top_t + 0.1
    (uphill edge — always the highest wall_top in the pocket footprint
    because tilt is mono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
    [case.scad]
2026-04-14 harden case invariant suite after JLC3DP SLA deep review
    Pre-fab review turned up four currently-satisfied-by-margin invariants
    with no assertion enforcing them, plus a stale arithmetic comment on
    slot_center_offset. Lock them into the suite so a future edit cannot
    silently erode the margin:
    - magnet ↔ USB cheek ≥ 2 mm (was just a non-overlap guard; real cheek
    today is 3.04 mm, keep 2 mm as the floor)
    - magnet notch clear of the overlay's rounded outer corner by
    ≥ overlay_corner_r
    - tongue recess inner edge ≥ 2 mm from every key_rect edge
    - USB × back-slot combined X+Z disjoint guard (belt-and-braces over
    the existing X-only check)
    - fix stale "(3.5 − 1.75)/2 = +0.875" comm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
    [case.scad]
2026-04-14 add 3D-print-only decorative trims to case.scad
    Cosmetic embellishments gated by ENABLE_DECORATIVE_TRIMS (master) plus
    per-feature toggles. Every cut is sized to JLC3DP design rules
    (>=0.8mm wide x >=0.8mm deep) for SLA resin and MJF nylon; flipping
    the master off produces a case byte-identical to the baseline.
    Features:
    - side-wall mKey logo deboss (both outer walls, shared deco_logo_2d)
    - overlay top-edge pinstripe groove, tilt-matched to the wedge top
    - owner initials + build-year stamp on the tray underside, mirrored
    in X so they read when the case is flipped over
    - mKey logo debossed above the display, centred on the display X
    using a measured "mKey" text extent
    The on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
    [case.scad]
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2026-04-16 add print-mode orientation, breakaway supports, and build script
    JLC3DP flagged deformation/warping risk on the case STLs due to the 5°
    wedge tilt and unsupported 363mm walls. Add PRINT_MODE and PRINT_SUPPORTS
    toggles to case.scad:
    - Overlay: flattened (tilt removed) and flipped cosmetic-face-down for
    best build-plate surface finish on SLA and FDM
    - Tray: 3 breakaway cross-braces spanning the opening to hold walls at
    correct spacing during SLA cure (0.4mm snap-off necks at wall junctions)
    Add build_stl.sh to drive OpenSCAD CLI for STL export (--supports,
    --piece, --fn flags; defaults to $fn=128 for production curves).
    Remove committed STLs from git tracking — they are now build art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
    [case.scad, mkey_overlay.stl, mkey_tray.stl]
2026-04-16 fix overlay print-mode chirality: mirror → rotate
    mirror([0,0,1]) reverses handedness, which inverts all debossed text
    and logos on the cosmetic face. Replace with rotate([0,180,0]) which
    flips Z (cosmetic face down) and X (compensated by translate) while
    preserving chirality. Bounding box and Z positioning are unchanged.
    [case.scad]
2026-04-16 fix 3 pre-fab review issues in case.scad for JLC3DP SLA
    Full design review against JLC3DP SLA design rules found three issues:
    1. Owner initials chirality (deco_owner_initials): mirror([1,0,0]) →
    mirror([0,1,0]). Flipping the case toward the viewer rotates around X,
    which negates Y but preserves X — the old X-mirror produced backwards
    text; Y-mirror correctly pre-compensates the vertical glyph inversion.
    2. Year text stroke width (deco_year_size): 3.8 → 5.0 mm. At 3.8 mm cap
    height, the thinnest strokes of "2026" in Liberation Sans Bold are
    ~0.6–0.7 mm, below JLC3DP's 0.8 mm engraved-detail minimum.
    3. Breakaway brace neck (brace_neck): 0.4 → 0.8 mm. 0.4 mm is bel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
    [case.scad]
2026-04-16 move support braces to avoid gasket slot X-ranges
    The 3 braces at uniform quarter-points (X = 90.8, 181.6, 272.4) all
    landed directly on back-wall gasket slots, filling in the open-top
    channels that plate tabs descend through during assembly.
    Replaced with 4 braces placed at the midpoints of the widest gaps
    between front-wall and back-wall slot X-ranges:
    Brace X (case): 71.5 120.2 207.8 294.5
    Nearest slot: 14.7mm 11.3mm 15.7mm 14.0mm (edge clearance)
    Max unsupported span is 87.6 mm (braces 2→3), comparable to the
    original 90.8 mm quarter-point spacing. The extra brace improves
    anti-warp stiffness slightly.
    [case.scad]
2026-04-16 beef up cross-braces for effective SLA anti-warp resistance
    The old 2×1.5 mm brace cross-section (I = 0.56 mm⁴) had negligible
    bending stiffness over the ~101 mm cavity span — the walls could
    push them aside with trivial force.
    New 3×4 mm cross-section (I = 16.0 mm⁴) gives 29× more stiffness,
    enough to meaningfully resist the lateral forces from ~0.3% cure
    shrinkage trying to bow the 363 mm front/back walls during UV
    post-cure.
    brace_w: 2.0 → 3.0 mm (linear stiffness gain)
    brace_h: 1.5 → 4.0 mm (h³ scaling: 4.7× from height alone)
    brace_neck: 0.8 mm unchanged (knife separation)
    [case.scad]
2026-04-16 replace cross-braces with internal rib walls for SLA anti-warp
    The old cross-braces sat on top of the tray walls — the very last
    layers to print. By the time they existed, the 363 mm long walls had
    already warped under cure shrinkage from every preceding layer. The
    braces were structurally useless for their stated purpose.
    New approach: vertical rib walls inside the cavity, running from the
    floor to just below the wall tops, front wall to back wall. These
    grow SIMULTANEOUSLY with the tray walls during the SLA build, so
    anti-warp resistance is present from the first wall layer.
    Each rib creates a T-section where it meets the long front/back
    walls, dramatically increasing the second moment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
    [case.scad]
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2026-04-16 tighten JLC3DP SLA pre-fab review items for prototype submission
    Pre-fab review surfaced two must-fix items and three quick wins:
    1. slot_tol 0.4 → 0.6: the ±0.3% SLA tolerance on the 363 mm case gives
    ~1 mm positional drift at the outermost tabs (case-X ≈ 320), which
    would jam a 0.2 mm-play slot. 0.6 restores 0.3 mm/side play.
    2. rib_neck 0.8 → 1.0: 0.8 mm worst-cased to 0.6 mm under ±0.2 mm SLA
    tolerance, below the JLC3DP 0.8 mm feature-minimum floor.
    3. 5th anti-warp rib at x=252: old 4-rib layout left 87.6 mm between
    ribs 2→3, above the ≤75 mm rule-of-thumb for 363 mm SLA parts.
    4. Raise decorative features off the 0.8 mm floor:
    - deco_cut_depth 0.8 → 1.0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
    [case.scad]
2026-04-16 add floor-level breakaway neck and perforate all three neck seams
    The rib's bottom edge was fused to the case floor along its full ~101 mm
    span with no breakaway — impossible to snap out cleanly. Added a third
    breakaway neck along the floor, matching the front/back wall pattern.
    Then perforated all three neck seams into discrete attachment segments
    so SLA crack propagation only has to travel ~1 segment before hitting
    a free edge:
    - floor: 5 gaps → 6 segments of ~13.5 mm each
    - each wall: 2 gaps → 3 segments (~4.8 mm front, ~8 mm back)
    Floor perforation is aggressive (floor attachment doesn't carry the
    anti-warp load); wall perforation is minimal to preserve the T-section
    bracing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
    [case.scad]
2026-04-17 shrink magnet pockets to clear JLC3DP hole tolerance and add mid-wall pair
    The 2026-04-17 pre-fab review caught that JLC3DP's SLA hole tolerance is
    ±0.3 mm (not the ±0.2 mm general dimensional rule). With the prior Ø3.2 mm
    pocket for a Ø3.0 mm magnet that meant a worst-case 2.9 mm bore — tighter
    than the magnet itself. Growing the pocket to clear the rule would have
    dropped the wall cheek below JLC3DP's 0.8 mm wall-thickness floor, so the
    magnet gets smaller instead: Ø2×1 N52 in an Ø2.5×2.0 mm pocket.
    While here, add a 5th/6th magnet position at the middle of the front and
    back walls to recover hold force (6×80 g ≈ 480 g, vs 4×80 g = 320 g after
    downsizing). The back-middle po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
    [case.scad]
2026-04-17 widen cosmetic strokes and tongue to clear JLC3DP slop margins
    Part of the 2026-04-17 pre-fab review (B–F marginals). Previous values
    sat exactly on JLC3DP floors; these bumps give ≥0.2 mm headroom so the
    full ±0.2 mm SLA fab slop fits inside the margin without narrowing any
    printed feature below spec.
    - deco_stripe_width 0.9 → 1.0 mm (pinstripe groove)
    - deco_year_size 5.5 → 6.0 mm (underside year row, stroke 0.90 mm)
    - deco_logo_text_size 5.5 → 6.0 mm (side-wall wordmark, stroke 0.90 mm)
    - deco_logo_chip_border 0.9 → 1.0 mm (chip icon frame)
    - rabbet_w 2.0 → 2.2 mm (tongue cross-section 1.5 → 1.7 mm)
    DECO_LOGO_TEXT_X_EXTENT_REF / _REF_SIZE remain an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
    [case.scad]
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2026-04-17 fix display pocket clearance and anti-warp rib spacing for JLC3DP
    - Increase disp_cut_tol from 0.20 to 0.30mm to meet JLC3DP's 0.2mm
    assembly clearance rule (0.20 left worst-case at 0.0mm clearance)
    - Add 6th anti-warp rib at X=161.8mm to close 87.6mm gap between
    ribs 2 and 3 (was above 75mm guideline for 363mm SLA parts)
    - All inter-rib spans now under 67mm
    [case.scad]
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

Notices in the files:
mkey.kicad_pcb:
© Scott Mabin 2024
